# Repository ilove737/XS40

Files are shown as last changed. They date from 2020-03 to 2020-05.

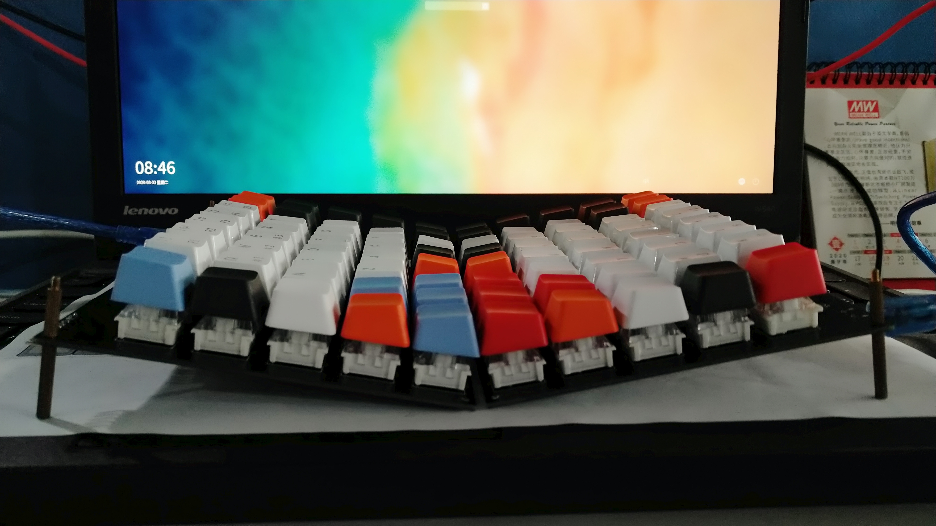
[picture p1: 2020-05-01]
doc/a8b779794b4cff2eecfce481d46be4e.jpg

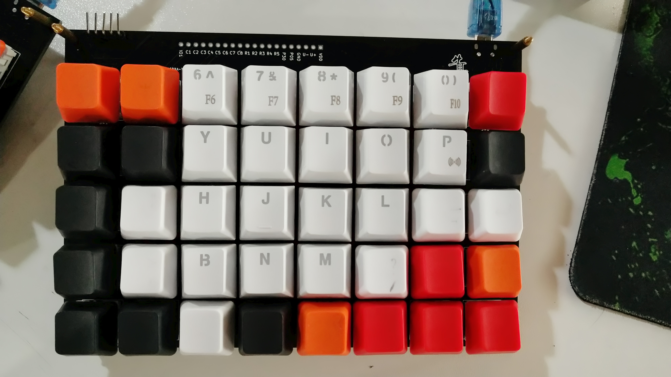
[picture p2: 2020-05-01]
doc/74a61ceb1c933b0123dbee454cc0db6.jpg

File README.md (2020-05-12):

# XS40

#### 介绍
80键分体键盘，采用非常便宜的单片机和USB HID接口芯片。目的就是打造一款低成本的机械键盘DIY方案。

hard 文件夹内是键盘的硬件设计文档，PCB设计使用的是KiCad开源软件。

soft 文件夹内是键盘的软件实现。逻辑部分用的是新唐的N76E003单片机。USB接口使用的是 CH9328 USB HID 芯片。

目前的键位设计可以通过  http://www.keyboard-layout-editor.com/#/  站点查看。
打开上述网页点击“Raw data”选项卡，粘贴一下内容即可渲染出键位设计。如有对键位设计有建议的可以在评论区留言，谢谢！
```
[{c:"#6495ed"},"Esc",{c:"#cccccc"},"!\n1","@\n2","#\n3","$\n4","%\n5",{c:"#ff4500"},"~\n`","*",{x:1},"_","+",{c:"#cccccc"},"^\n6","&\n7","*\n8","(\n9",")\n0",{c:"#bb0000"},"Bs"],
[{c:"#444444"},"Tab",{c:"#cccccc"},"Q","W","E","R","T",{c:"#444444"},"{\n[","}\n]",{x:1},"+\n=","|\n\\",{c:"#cccccc"},"Y","U","I","O","P",{c:"#444444"},"del"],
[{c:"#cccccc"},"Caps Lock","A","S","D","F","G","(",{c:"#444444"},")",{x:1},":\n;",{c:"#cccccc"},"<\n,","H","J","K","L","_\n-","Enter"],
[{c:"#ff4500"},"Shift",{c:"#6495ed"},"@",{c:"#cccccc"},"Z","X","C","V","&",{c:"#444444"},"#",{x:1},"\"\n'",{c:"#cccccc"},">\n.","B","N","M","?\n/",{c:"#bb0000"},"↑",{c:"#ff4500"},"RShift"],
[{c:"#6495ed"},"Fn0","Win","Alt",{c:"#ff4500"},"Shift",{c:"#cccccc"},"Space",{c:"#444444"},"Ctrl","~","!",{x:1},"%","?","Ctrl",{c:"#cccccc"},"Space",{c:"#ff4500"},"Fn0",{c:"#bb0000"},"←","↓","→"],

[{y:0.5,c:"#6495ed"},"F0",{c:"#cccccc"},"F1","F2","F3","F4","F5",{c:"#ff4500"},"Num Lock","",{x:1},"","",{c:"#cccccc"},"F6","F7","F8","F9","F10",{c:"#bb0000"},""],
[{c:"#444444"},"select",{c:"#cccccc"},"F11","F12","mail",{a:7},"","",{c:"#444444",a:4},"","",{x:1},"","",{c:"#cccccc"},"7\nHome",{a:4},"8\n↑","|",{a:4},"/","",{c:"#444444"},""],
[{c:"#cccccc"},"prev","play","next","stop",{a:7},"","",{a:4},"",{c:"#444444"},"",{x:1},"",{c:"#cccccc"},"","4\n←",{a:4},"\"",{a:4},":",{a:4},"*","",""],
[{c:"#ff4500",a:4},"vol dn",{c:"#6495ed"},"mute",{c:"#cccccc"},"vol up","app",{a:7},"","",{a:4},"",{c:"#444444"},"",{x:1},"",{c:"#cccccc"},"","1\nEnd","{","}","-",{c:"#bb0000",a:4},"",{c:"#ff4500"},""],
[{c:"#6495ed"},"Fn0","Fn2","Fn4",{c:"#ff4500",a:7},"",{c:"#cccccc"},"",{c:"#444444"},"",{a:4},"","",{x:1},"","","PEnter",{c:"#cccccc"},"0\nIns",{c:"#ff4500"},"Fn0",{c:"#bb0000"},"+","",""]

```

#### 展示
输入图片说明
输入图片说明
输入图片说明
输入图片说明

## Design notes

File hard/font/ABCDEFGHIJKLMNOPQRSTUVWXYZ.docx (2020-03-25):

ABCDEFGHIJKLMNOPQRSTUVWXYZ

abcdefghijklmnopqrstuvwxyz

!@#$%^&*()_+-=[]{}\|;:’”,<.>/?~`

shift tab caps ctrl alt esc enter fn backspace delete home end insert

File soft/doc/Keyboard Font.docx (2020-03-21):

Keyboard Font

ABCDEFGHIJKLMNOPQRSTUVWXYZ

abcdefghijklmnopqrstuvwxyz

!@#$%^&*()_+-=[]{};:’”,<.>/?`~\|

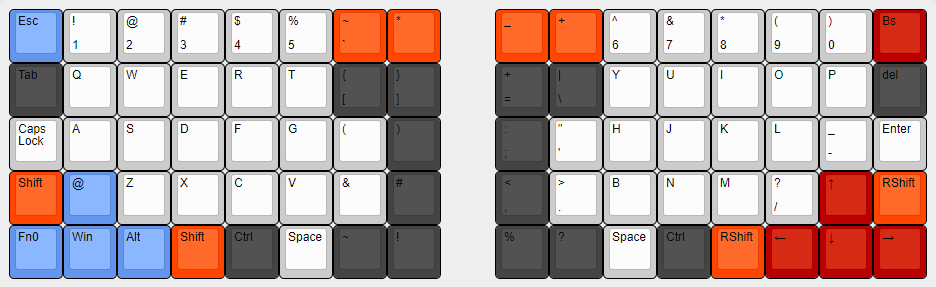
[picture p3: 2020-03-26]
soft/doc/keyMap.png

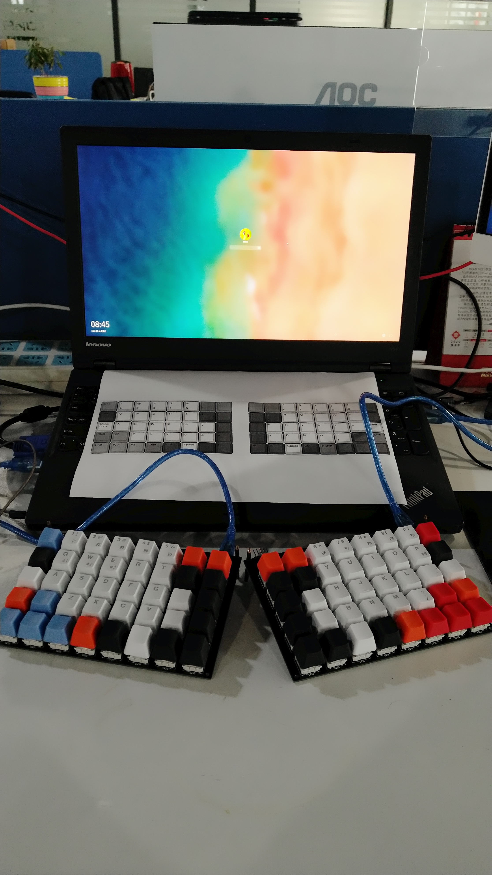
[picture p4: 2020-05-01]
doc/43c635f29237a9f031e426376ea0fd5.jpg

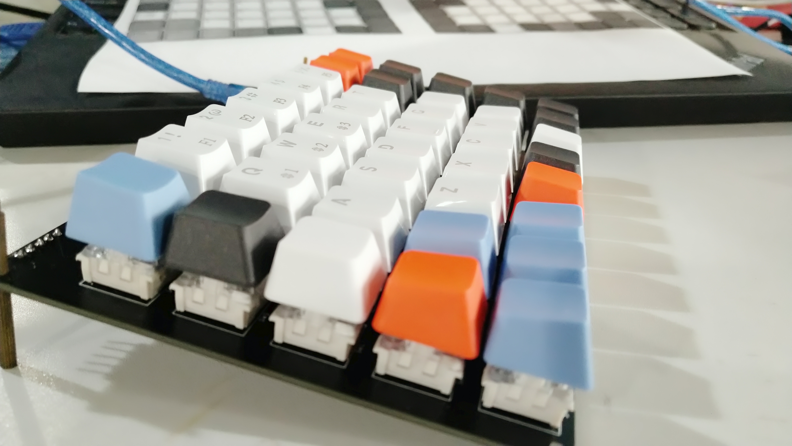
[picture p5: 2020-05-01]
doc/b146eeb9497ea70faab857080b56009.jpg

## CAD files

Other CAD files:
soft/Sample_Code/GPIO/Output/STARTUP.obj
soft/Sample_Code/GPIO/Output/Common.obj
soft/Sample_Code/GPIO/Output/Delay.obj
soft/Sample_Code/GPIO/Output/GPIO.obj

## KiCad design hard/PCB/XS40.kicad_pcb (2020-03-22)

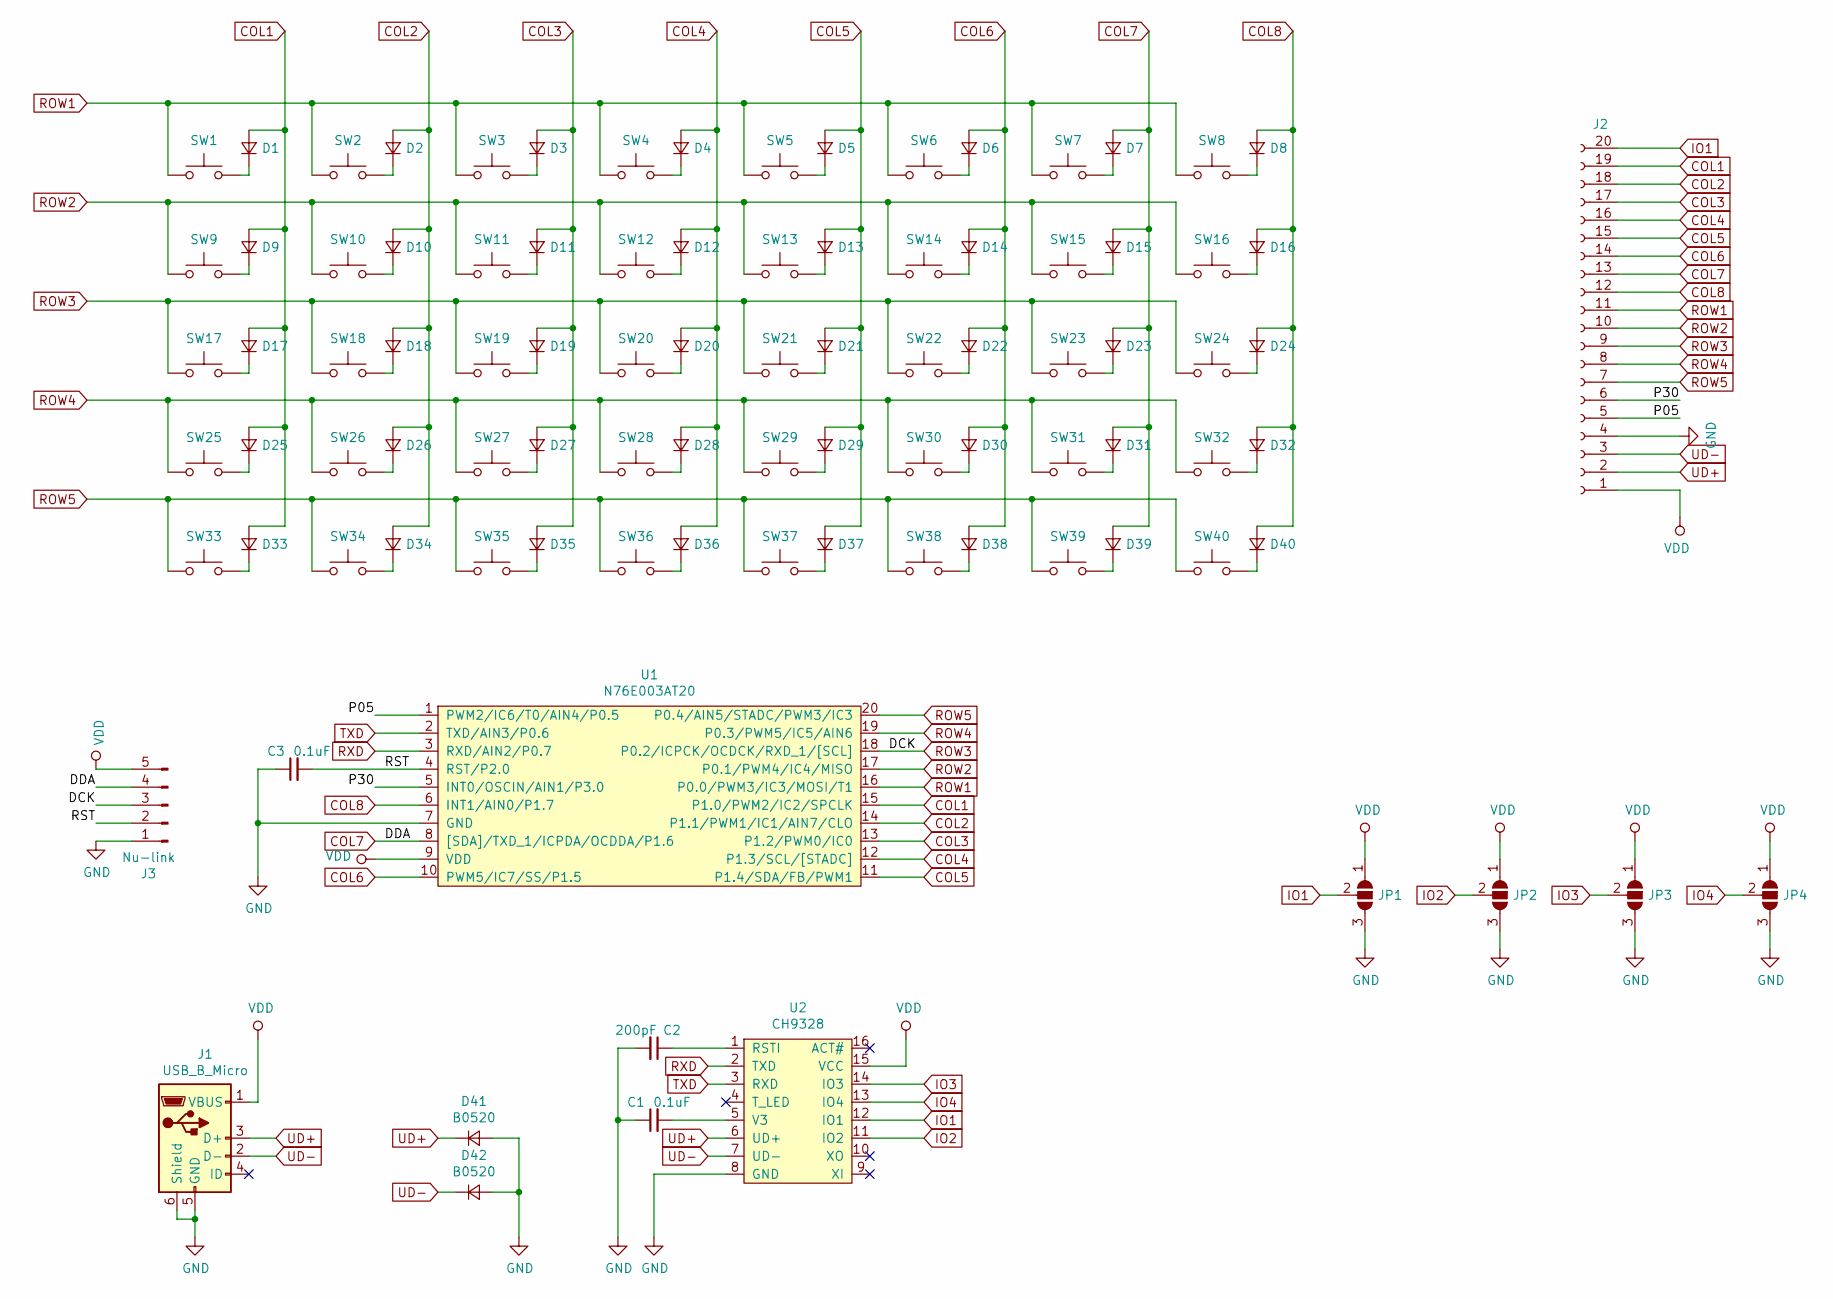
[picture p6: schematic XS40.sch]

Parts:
C1, C3: 0.1uF; C_0603_1608Metric
C2: 200pF; C_0603_1608Metric
D1, D2, D3, D4, D5, D6, D7, D8, D9, D10, D11, D12, D13, D14, D15, D16, D17, D18, D19, D20, D21, D22, D23, D24, D25, D26, D27, D28, D29, D30, D31, D32, D33, D34, D35, D36, D37, D38, D39, D40: D_Small; D_1206_3216Metric
D41, D42: B0520; D_SOD-123
J1: USB_B_Micro; USB_Micro-B_Molex-105017-0001
J2: Conn_01x20_Female; PinSocket_1x20_P2.54mm_Vertical
J3: Nu-link; PinSocket_1x05_P2.54mm_Vertical
JP1, JP2, JP3, JP4: SolderJumper_3_Open; SolderJumper-3_P1.3mm_Open_RoundedPad1.0x1.5mm_NumberLabels
SW1, SW2, SW3, SW4, SW5, SW6, SW7, SW8, SW9, SW10, SW11, SW12, SW13, SW14, SW15, SW16, SW17, SW18, SW19, SW20, SW21, SW22, SW23, SW24, SW25, SW26, SW27, SW28, SW29, SW30, SW31, SW32, SW33, SW34, SW35, SW36, SW37, SW38, SW39, SW40: SW_Push; SW_Cherry_MX_1.00u_PCB
U1: N76E003AT20; TSSOP-20_4.4x6.5mm_P0.65mm
U2: CH9328; SOP-16_4.55x10.3mm_P1.27mm

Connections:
/P05: J2.5, U1.1 (PWM2/IC6/T0/AIN4/P0.5)
/P30: J2.6, U1.5 (INT0/OSCIN/AIN1/P3.0)
/RST: C3.2, J3.2, U1.4 (RST/P2.0)
COL1: D1.2 (A), D9.2 (A), D17.2 (A), D25.2 (A), D33.2 (A), J2.19, U1.15 (P1.0/PWM2/IC2/SPCLK)
COL2: D2.2 (A), D10.2 (A), D18.2 (A), D26.2 (A), D34.2 (A), J2.18, U1.14 (P1.1/PWM1/IC1/AIN7/CLO)
COL3: D3.2 (A), D11.2 (A), D19.2 (A), D27.2 (A), D35.2 (A), J2.17, U1.13 (P1.2/PWM0/IC0)
COL4: D4.2 (A), D12.2 (A), D20.2 (A), D28.2 (A), D36.2 (A), J2.16, U1.12 (P1.3/SCL/[STADC])
COL5: D5.2 (A), D13.2 (A), D21.2 (A), D29.2 (A), D37.2 (A), J2.15, U1.11 (P1.4/SDA/FB/PWM1)
COL6: D6.2 (A), D14.2 (A), D22.2 (A), D30.2 (A), D38.2 (A), J2.14, U1.10 (PWM5/IC7/SS/P1.5)
COL7: D7.2 (A), D15.2 (A), D23.2 (A), D31.2 (A), D39.2 (A), J2.13, J3.4, U1.8 ([SDA]/TXD_1/ICPDA/OCDDA/P1.6)
COL8: D8.2 (A), D16.2 (A), D24.2 (A), D32.2 (A), D40.2 (A), J2.12, U1.6 (INT1/AIN0/P1.7)
GND: C1.1, C2.2, C3.1, D41.2 (A), D42.2 (A), J1.5 (GND), J1.6 (Shield), J2.4, J3.1, JP1.3 (B), JP2.3 (B), JP3.3 (B), JP4.3 (B), U1.7 (GND), U2.8 (GND)
IO1: J2.20, JP1.2 (C), U2.12 (IO1)
IO2: JP2.2 (C), U2.11 (IO2)
IO3: JP3.2 (C), U2.14 (IO3)
IO4: JP4.2 (C), U2.13 (IO4)
unnamed: C1.2, U2.5 (V3)
unnamed: C2.1, U2.1 (RSTI)
unnamed: D1.1 (K), SW1.2
unnamed: D2.1 (K), SW2.2
unnamed: D3.1 (K), SW3.2
unnamed: D4.1 (K), SW4.2
unnamed: D5.1 (K), SW5.2
unnamed: D6.1 (K), SW6.2
unnamed: D7.1 (K), SW7.2
unnamed: D8.1 (K), SW8.2
unnamed: D9.1 (K), SW9.2
unnamed: D10.1 (K), SW10.2
unnamed: D11.1 (K), SW11.2
unnamed: D12.1 (K), SW12.2
unnamed: D13.1 (K), SW13.2
unnamed: D14.1 (K), SW14.2
unnamed: D15.1 (K), SW15.2
unnamed: D16.1 (K), SW16.2
unnamed: D17.1 (K), SW17.2
unnamed: D18.1 (K), SW18.2
unnamed: D19.1 (K), SW19.2
unnamed: D20.1 (K), SW20.2
unnamed: D21.1 (K), SW21.2
unnamed: D22.1 (K), SW22.2
unnamed: D23.1 (K), SW23.2
unnamed: D24.1 (K), SW24.2
unnamed: D25.1 (K), SW25.2
unnamed: D26.1 (K), SW26.2
unnamed: D27.1 (K), SW27.2
unnamed: D28.1 (K), SW28.2
unnamed: D29.1 (K), SW29.2
unnamed: D30.1 (K), SW30.2
unnamed: D31.1 (K), SW31.2
unnamed: D32.1 (K), SW32.2
unnamed: D33.1 (K), SW33.2
unnamed: D34.1 (K), SW34.2
unnamed: D35.1 (K), SW35.2
unnamed: D36.1 (K), SW36.2
unnamed: D37.1 (K), SW37.2
unnamed: D38.1 (K), SW38.2
unnamed: D39.1 (K), SW39.2
unnamed: D40.1 (K), SW40.2
ROW1: J2.11, SW1.1, SW2.1, SW3.1, SW4.1, SW5.1, SW6.1, SW7.1, SW8.1, U1.16 (P0.0/PWM3/IC3/MOSI/T1)
ROW2: J2.10, SW9.1, SW10.1, SW11.1, SW12.1, SW13.1, SW14.1, SW15.1, SW16.1, U1.17 (P0.1/PWM4/IC4/MISO)
ROW3: J2.9, J3.3, SW17.1, SW18.1, SW19.1, SW20.1, SW21.1, SW22.1, SW23.1, SW24.1, U1.18 (P0.2/ICPCK/OCDCK/RXD_1/[SCL])
ROW4: J2.8, SW25.1, SW26.1, SW27.1, SW28.1, SW29.1, SW30.1, SW31.1, SW32.1, U1.19 (P0.3/PWM5/IC5/AIN6)
ROW5: J2.7, SW33.1, SW34.1, SW35.1, SW36.1, SW37.1, SW38.1, SW39.1, SW40.1, U1.20 (P0.4/AIN5/STADC/PWM3/IC3)
RXD: U1.3 (RXD/AIN2/P0.7), U2.2 (TXD)
TXD: U1.2 (TXD/AIN3/P0.6), U2.3 (RXD)
UD+: D41.1 (K), J1.3 (D+), J2.2, U2.6 (UD+)
UD-: D42.1 (K), J1.2 (D-), J2.3, U2.7 (UD-)
VDD: J1.1 (VBUS), J2.1, J3.5, JP1.1 (A), JP2.1 (A), JP3.1 (A), JP4.1 (A), U1.9 (VDD), U2.15 (VCC)

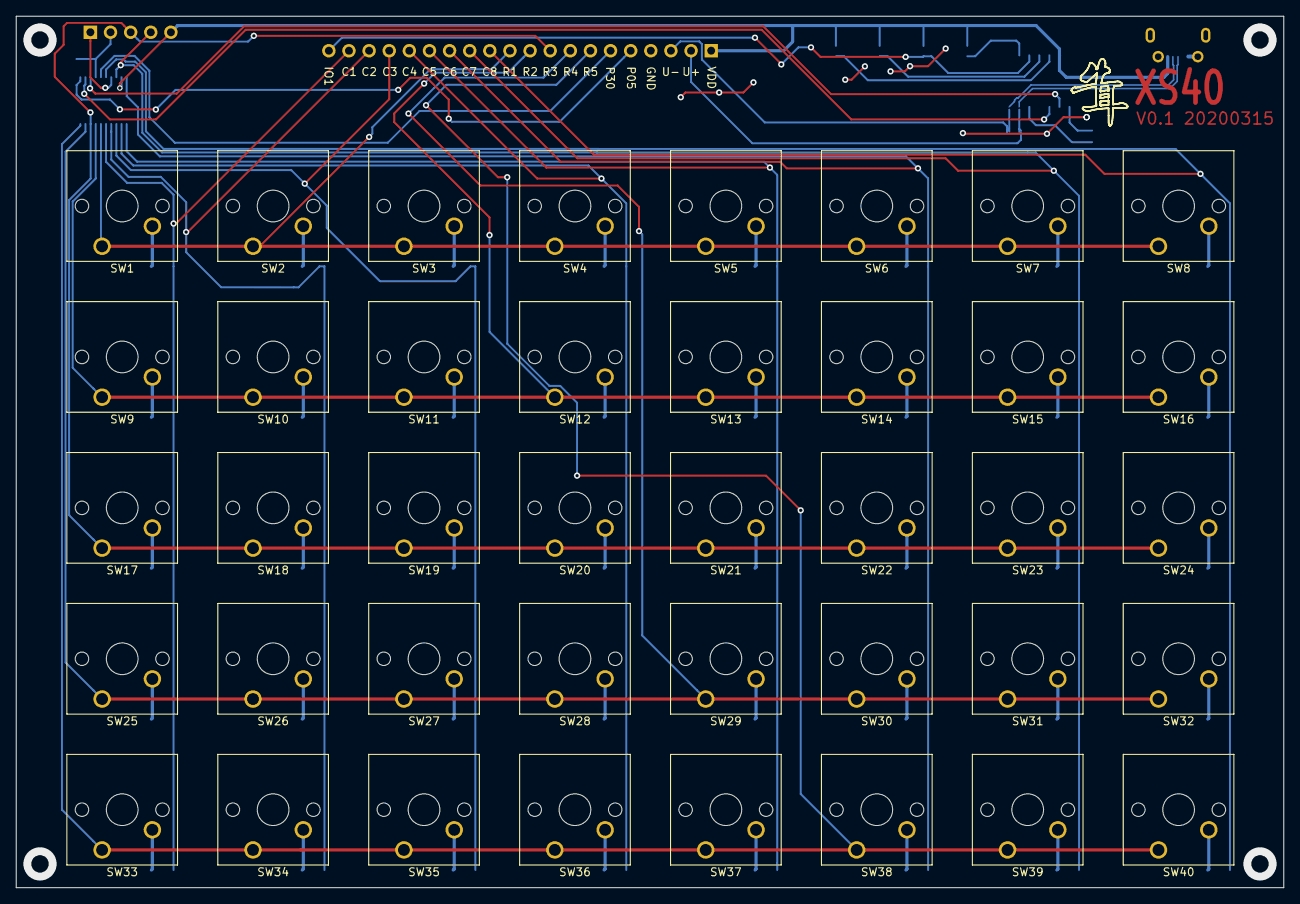
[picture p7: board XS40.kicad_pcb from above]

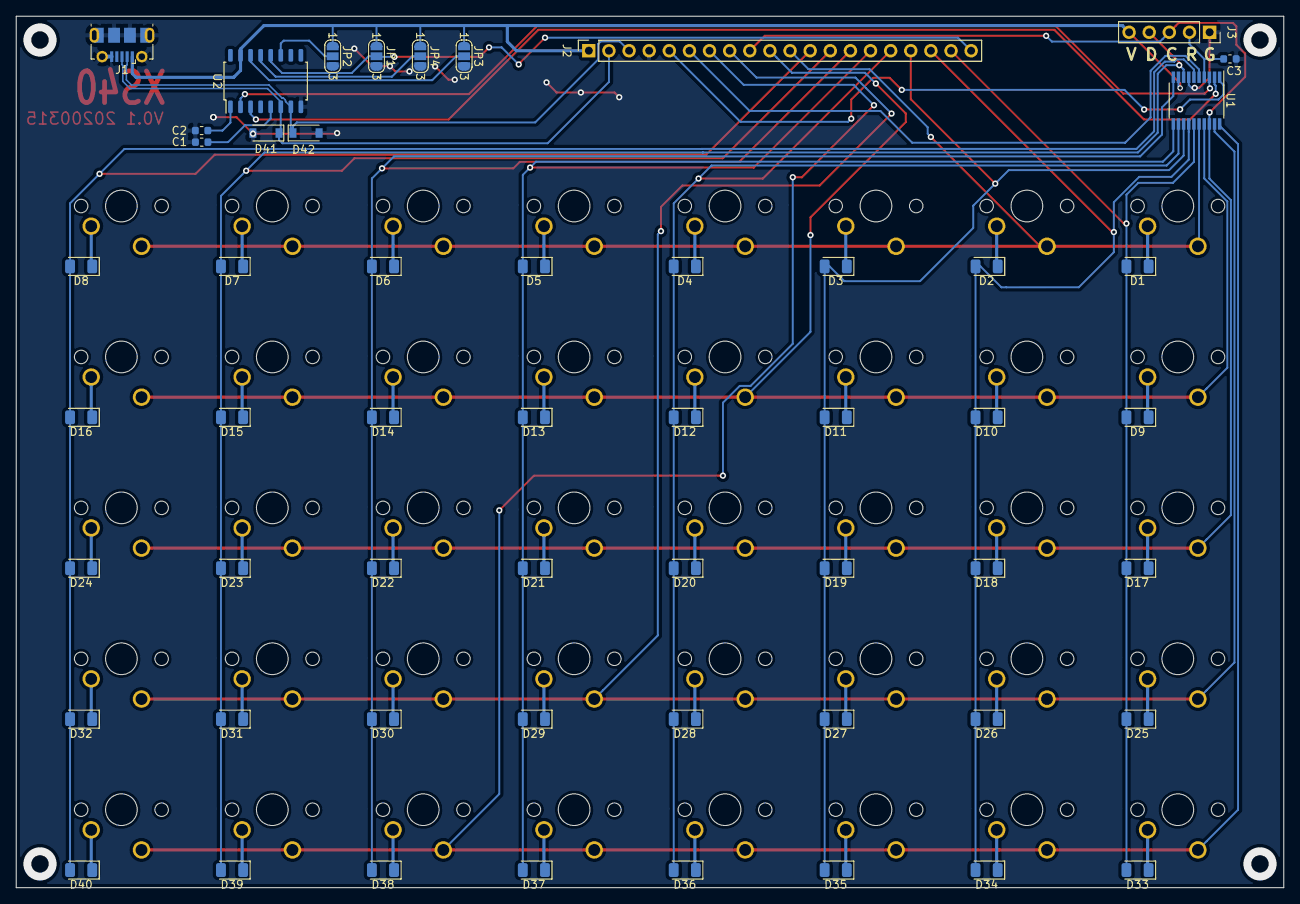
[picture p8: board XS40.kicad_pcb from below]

Board: 2 copper layers, 160.0 x 110.0 mm, 94 parts (54 on the bottom side), 68 nets.

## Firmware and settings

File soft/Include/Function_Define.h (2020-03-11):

#include <intrins.h>
#include <stdio.h>

#define nop _nop_();


//16 --> 8 x 2
#define HIBYTE(v1)              ((UINT8)((v1)>>8))                      //v1 is UINT16
#define LOBYTE(v1)              ((UINT8)((v1)&0xFF))
//8 x 2 --> 16
#define MAKEWORD(v1,v2)         ((((UINT16)(v1))<<8)+(UINT16)(v2))      //v1,v2 is UINT8
//8 x 4 --> 32
#define MAKELONG(v1,v2,v3,v4)   (UINT32)((v1<<32)+(v2<<16)+(v3<<8)+v4)  //v1,v2,v3,v4 is UINT8
//32 --> 16 x 2
#define YBYTE1(v1)              ((UINT16)((v1)>>16))                    //v1 is UINT32
#define YBYTE0(v1)              ((UINT16)((v1)&0xFFFF))
//32 --> 8 x 4
#define TBYTE3(v1)              ((UINT8)((v1)>>24))                     //v1 is UINT32
#define TBYTE2(v1)              ((UINT8)((v1)>>16))
#define TBYTE1(v1)              ((UINT8)((v1)>>8)) 
#define TBYTE0(v1)              ((UINT8)((v1)&0xFF))

#define SET_BIT0        0x01
#define SET_BIT1        0x02
#define SET_BIT2        0x04
#define SET_BIT3        0x08
#define SET_BIT4        0x10
#define SET_BIT5        0x20
#define SET_BIT6        0x40
#define SET_BIT7        0x80
#define SET_BIT8        0x0100
#define SET_BIT9        0x0200
#define SET_BIT10       0x0400
#define SET_BIT11       0x0800
#define SET_BIT12       0x1000
#define SET_BIT13       0x2000
#define SET_BIT14       0x4000
#define SET_BIT15       0x8000

#define CLR_BIT0        0xFE
#define CLR_BIT1        0xFD
#define CLR_BIT2        0xFB
#define CLR_BIT3        0xF7
#define CLR_BIT4        0xEF
#define CLR_BIT5        0xDF
#define CLR_BIT6        0xBF
#define CLR_BIT7        0x7F

#define CLR_BIT8        0xFEFF
#define CLR_BIT9        0xFDFF
#define CLR_BIT10       0xFBFF
#define CLR_BIT11       0xF7FF
#define CLR_BIT12       0xEFFF
#define CLR_BIT13       0xDFFF
#define CLR_BIT14       0xBFFF
#define CLR_BIT15       0x7FFF

#define FAIL            1
#define PASS            0

/*****************************************************************************************
* For GPIO INIT setting 
*****************************************************************************************/
//------------------- Define Port as Quasi mode  -------------------
#define P00_Quasi_Mode				P0M1&=~SET_BIT0;P0M2&=~SET_BIT0
#define P01_Quasi_Mode				P0M1&=~SET_BIT1;P0M2&=~SET_BIT1
#define P02_Quasi_Mode				P0M1&=~SET_BIT2;P0M2&=~SET_BIT2
#define P03_Quasi_Mode				P0M1&=~SET_BIT3;P0M2&=~SET_BIT3
#define P04_Quasi_Mode				P0M1&=~SET_BIT4;P0M2&=~SET_BIT4
#define P05_Quasi_Mode				P0M1&=~SET_BIT5;P0M2&=~SET_BIT5
#define P06_Quasi_Mode				P0M1&=~SET_BIT6;P0M2&=~SET_BIT6
#define P07_Quasi_Mode				P0M1&=~SET_BIT7;P0M2&=~SET_BIT7
#define P10_Quasi_Mode				P1M1&=~SET_BIT0;P1M2&=~SET_BIT0
#define P11_Quasi_Mode				P1M1&=~SET_BIT1;P1M2&=~SET_BIT1
#define P12_Quasi_Mode				P1M1&=~SET_BIT2;P1M2&=~SET_BIT2
#define P13_Quasi_Mode				P1M1&=~SET_BIT3;P1M2&=~SET_BIT3
#define P14_Quasi_Mode				P1M1&=~SET_BIT4;P1M2&=~SET_BIT4
#define P15_Quasi_Mode				P1M1&=~SET_BIT5;P1M2&=~SET_BIT5
#define P16_Quasi_Mode				P1M1&=~SET_BIT6;P1M2&=~SET_BIT6
#define P17_Quasi_Mode				P1M1&=~SET_BIT7;P1M2&=~SET_BIT7
#define P30_Quasi_Mode				P3M1&=~SET_BIT0;P3M2&=~SET_BIT0
//------------------- Define Port as Push Pull mode -------------------
#define P00_PushPull_Mode			P0M1&=~SET_BIT0;P0M2|=SET_BIT0
#define P01_PushPull_Mode			P0M1&=~SET_BIT1;P0M2|=SET_BIT1
#define P02_PushPull_Mode			P0M1&=~SET_BIT2;P0M2|=SET_BIT2
#define P03_PushPull_Mode			P0M1&=~SET_BIT3;P0M2|=SET_BIT3
#define P04_PushPull_Mode			P0M1&=~SET_BIT4;P0M2|=SET_BIT4
#define P05_PushPull_Mode			P0M1&=~SET_BIT5;P0M2|=SET_BIT5
#define P06_PushPull_Mode			P0M1&=~SET_BIT6;P0M2|=SET_BIT6
#define P07_PushPull_Mode			P0M1&=~SET_BIT7;P0M2|=SET_BIT7
#define P10_PushPull_Mode			P1M1&=~SET_BIT0;P1M2|=SET_BIT0
#define P11_PushPull_Mode			P1M1&=~SET_BIT1;P1M2|=SET_BIT1
#define P12_PushPull_Mode			P1M1&=~SET_BIT2;P1M2|=SET_BIT2
#define P13_PushPull_Mode			P1M1&=~SET_BIT3;P1M2|=SET_BIT3
#define P14_PushPull_Mode			P1M1&=~SET_BIT4;P1M2|=SET_BIT4
#define P15_PushPull_Mode			P1M1&=~SET_BIT5;P1M2|=SET_BIT5
#define P16_PushPull_Mode			P1M1&=~SET_BIT6;P1M2|=SET_BIT6
#define P17_PushPull_Mode			P1M1&=~SET_BIT7;P1M2|=SET_BIT7
#define P30_PushPull_Mode			P3M1&=~SET_BIT0;P3M2|=SET_BIT0
#define GPIO1_PushPull_Mode		P1M1&=~SET_BIT0;P1M2|=SET_BIT0
//------------------- Define Port as Input Only mode -------------------
#define P00_Input_Mode				P0M1|=SET_BIT0;P0M2&=~SET_BIT0
#define P01_Input_Mode				P0M1|=SET_BIT1;P0M2&=~SET_BIT1
#define P02_Input_Mode				P0M1|=SET_BIT2;P0M2&=~SET_BIT2
#define P03_Input_Mode				P0M1|=SET_BIT3;P0M2&=~SET_BIT3
#define P04_Input_Mode				P0M1|=SET_BIT4;P0M2&=~SET_BIT4
#define P05_Input_Mode				P0M1|=SET_BIT5;P0M2&=~SET_BIT5
#define P06_Input_Mode				P0M1|=SET_BIT6;P0M2&=~SET_BIT6
#define P07_Input_Mode				P0M1|=SET_BIT7;P0M2&=~SET_BIT7
#define P10_Input_Mode				P1M1|=SET_BIT0;P1M2&=~SET_BIT0
#define P11_Input_Mode				P1M1|=SET_BIT1;P1M2&=~SET_BIT1
#define P12_Input_Mode				P1M1|=SET_BIT2;P1M2&=~SET_BIT2
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

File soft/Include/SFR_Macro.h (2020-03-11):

/**** P0		80H *****/
#define set_P00			P00		=		1
#define set_P01			P01		=		1
#define set_P02			P02		=		1
#define set_P03			P03		=		1
#define set_P04			P04		=		1
#define set_P05			P05		=		1
#define set_P06			P06		=		1
#define set_P07			P07		=		1

#define clr_P00			P00		=		0
#define clr_P01			P01		=		0
#define clr_P02			P02		=		0
#define clr_P03			P03		=		0
#define clr_P04			P04		=		0
#define clr_P05			P05		=		0
#define clr_P06			P06		=		0
#define clr_P07			P07		=		0

//**** SP  	81H **** 
//**** DPH  82H **** 
//**** DPL  83H **** 
//**** RWK  86H **** 

//**** PCON	87H *****
#define set_SMOD    PCON    |= SET_BIT7
#define set_SMOD0   PCON    |= SET_BIT6
#define set_POF     PCON    |= SET_BIT4
#define set_GF1     PCON    |= SET_BIT3
#define set_GF0     PCON    |= SET_BIT2 
#define set_PD      PCON    |= SET_BIT1
#define set_IDL    	PCON    |= SET_BIT0
                            
#define clr_SMOD    PCON    &= ~SET_BIT7
#define clr_SMOD0   PCON    &= ~SET_BIT6
#define clr_POF     PCON    &= ~SET_BIT4
#define clr_GF1     PCON    &= ~SET_BIT3
#define clr_GF0     PCON    &= ~SET_BIT2 
#define clr_PD      PCON    &= ~SET_BIT1
#define clr_IDL    	PCON    &= ~SET_BIT0

/**** TCON		88H ****/
#define set_TF1			TF1		=		1
#define set_TR1			TR1		=		1
#define set_TF0			TF0		=		1
#define set_TR0			TR0		=		1
#define set_IE1			IE1		=		1
#define set_IT1			IT1		=		1
#define set_IE0			IE0		=		1
#define set_IT0			IT0		=		1

#define clr_TF1			TF1		=		0
#define clr_TR1			TR1		=		0
#define clr_TF0			TF0		=		0
#define clr_TR0			TR0		=		0
#define clr_IE1			IE1		=		0
#define clr_IT1			IT1		=		0
#define clr_IE0			IE0		=		0
#define clr_IT0			IT0		=		0

//**** TMOD		89H **** 
#define set_GATE_T1 	TMOD 		|= 	SET_BIT7
#define set_CT_T1 		TMOD   	|= 	SET_BIT6
#define set_M1_T1 		TMOD  	|= 	SET_BIT5
#define set_M0_T1 		TMOD   	|= 	SET_BIT4
#define set_GATE_T0 	TMOD 		|= 	SET_BIT3
#define set_CT_T0 		TMOD 	  |= 	SET_BIT2
#define set_M1_T0 		TMOD   	|= 	SET_BIT1
#define set_M0_T0 		TMOD   	|= 	SET_BIT0
                            
#define clr_GATE_T1 	TMOD 		&= 	~SET_BIT7
#define clr_CT_T1 		TMOD   	&= 	~SET_BIT6
#define clr_M1_T1 		TMOD   	&= 	~SET_BIT5
#define clr_M0_T1 		TMOD   	&= 	~SET_BIT4
#define clr_GATE_T0 	TMOD 		&= 	~SET_BIT3
#define clr_CT_T0 		TMOD   	&= 	~SET_BIT2
#define clr_M1_T0 		TMOD   	&= 	~SET_BIT1
#define clr_M0_T0 		TMOD   	&= 	~SET_BIT0

//**** TH1		8AH **** 
//**** TH0		8BH **** 
//**** TL1		8CH	**** 
//**** TL0		8DH **** 

//**** CKCON	8EH ****
#define set_PWMCKS  CKCON   |= SET_BIT6
#define set_T1M     CKCON   |= SET_BIT4
#define set_T0M     CKCON   |= SET_BIT3
#define set_CLOEN   CKCON   |= SET_BIT1
                            
#define clr_PWMCKS  CKCON   &= ~SET_BIT6
#define clr_T1M     CKCON   &= ~SET_BIT4
#define clr_T0M     CKCON   &= ~SET_BIT3
#define clr_CLOEN   CKCON   &= ~SET_BIT1

//**** WKCON	8FH ****
#define set_WKTCK   WKCON   |= SET_BIT5
#define set_WKTF    WKCON   |= SET_BIT4
#define set_WKTR    WKCON   |= SET_BIT3
#define set_WKPS2   WKCON   |= SET_BIT2
#define set_WKPS1   WKCON   |= SET_BIT1
#define set_WKPS0   WKCON   |= SET_BIT0
                            
#define clr_WKTCK   WKCON   &= ~SET_BIT5
#define clr_WKTF    WKCON   &= ~SET_BIT4
#define clr_WKTR    WKCON   &= ~SET_BIT3
#define clr_WKPS2   WKCON   &= ~SET_BIT2
#define clr_WKPS1   WKCON   &= ~SET_BIT1
#define clr_WKPS0   WKCON   &= ~SET_BIT0

/**** P1		90H *****/
#define set_P10			P10		=		1
#define set_P11			P11		=		1
#define set_P12			P12		=		1
#define set_P13			P13		=		1
#define set_P14			P14		=		1
#define set_P15			P15		=		1
#define set_P16			P16		=		1
#define set_P17			P17		=		1

#define clr_P10			P10		=		0
#define clr_P11			P11		=		0
#define clr_P12			P12		=		0
#define clr_P13			P13		=		0
#define clr_P14			P14		=		0
#define clr_P15			P15		=		0
#define clr_P16			P16		=		0
#define clr_P17			P17		=		0

//****SFRS		91H ****
#define set_SFRPAGE  BIT_TMP=EA;EA=0;TA=0xAA;TA=0x55;SFRS|=SET_BIT0;EA=BIT_TMP
#define clr_SFRPAGE  BIT_TMP=EA;EA=0;TA=0xAA;TA=0x55;SFRS&=~SET_BIT0;EA=BIT_TMP

//****CAPCON0	92H ****
#define set_CAPEN2  CAPCON0 |= SET_BIT6
#define set_CAPEN1  CAPCON0 |= SET_BIT5
#define set_CAPEN0  CAPCON0 |= SET_BIT4
#define set_CAPF2   CAPCON0 |= SET_BIT2
#define set_CAPF1   CAPCON0 |= SET_BIT1
#define set_CAPF0   CAPCON0 |= SET_BIT0

#define clr_CAPEN2  CAPCON0 &= ~SET_BIT6
#define clr_CAPEN1  CAPCON0 &= ~SET_BIT5
#define clr_CAPEN0  CAPCON0 &= ~SET_BIT4
#define clr_CAPF2   CAPCON0 &= ~SET_BIT2
#define clr_CAPF1   CAPCON0 &= ~SET_BIT1
#define clr_CAPF0   CAPCON0 &= ~SET_BIT0

//**** CAPCON1	93H ****
#define set_CAP2LS1 CAPCON1 |= SET_BIT5
#define set_CAP2LS0 CAPCON1 |= SET_BIT4
#define set_CAP1LS1 CAPCON1 |= SET_BIT3
#define set_CAP1LS0 CAPCON1 |= SET_BIT2
#define set_CAP0LS1 CAPCON1 |= SET_BIT1
#define set_CAP0LS0 CAPCON1 |= SET_BIT0

#define clr_CAP2LS1 CAPCON1 &= ~SET_BIT5
#define clr_CAP2LS0 CAPCON1 &= ~SET_BIT4
#define clr_CAP1LS1 CAPCON1 &= ~SET_BIT3
#define clr_CAP1LS0 CAPCON1 &= ~SET_BIT2
#define clr_CAP0LS1 CAPCON1 &= ~SET_BIT1
#define clr_CAP0LS0 CAPCON1 &= ~SET_BIT0

//**** CAPCON2		94H ****
#define set_ENF2  CAPCON2   |= SET_BIT6
#define set_ENF1  CAPCON2   |= SET_BIT5
#define set_ENF0  CAPCON2   |= SET_BIT4
                            
#define clr_ENF2  CAPCON2   &= ~SET_BIT6
#define clr_ENF1  CAPCON2   &= ~SET_BIT5
#define clr_ENF0  CAPCON2   &= ~SET_BIT4

//**** CKDIV		95H ****

//**** CKSWT		96H ****  TA protect register
#define set_HIRCST  BIT_TMP=EA;EA=0;TA=0xAA;TA=0x55;CKSWT|=SET_BIT5;EA=BIT_TMP;
#define set_LIRCST  BIT_TMP=EA;EA=0;TA=0xAA;TA=0x55;CKSWT|=SET_BIT4;EA=BIT_TMP;
#define set_ECLKST  BIT_TMP=EA;EA=0;TA=0xAA;TA=0x55;CKSWT|=SET_BIT3;EA=BIT_TMP;
#define set_OSC1    BIT_TMP=EA;EA=0;TA=0xAA;TA=0x55;CKSWT|=SET_BIT2;EA=BIT_TMP;
#define set_OSC0    BIT_TMP=EA;EA=0;TA=0xAA;TA=0x55;CKSWT|=SET_BIT1;EA=BIT_TMP;

#define clr_HIRCST  BIT_TMP=EA;EA=0;TA=0xAA;TA=0x55;CKSWT&=~SET_BIT5;EA=BIT_TMP;
#define clr_LIRCST  BIT_TMP=EA;EA=0;TA=0xAA;TA=0x55;CKSWT&=~SET_BIT4;EA=BIT_TMP;
#define clr_ECLKST  BIT_TMP=EA;EA=0;TA=0xAA;TA=0x55;CKSWT&=~SET_BIT3;EA=BIT_TMP;
#define clr_OSC1    BIT_TMP=EA;EA=0;TA=0xAA;TA=0x55;CKSWT&=~SET_BIT2;EA=BIT_TMP;
#define clr_OSC0    BIT_TMP=EA;EA=0;TA=0xAA;TA=0x55;CKSWT&=~SET_BIT1;EA=BIT_TMP;

//**** CKEN 	97H **** TA protect register
#define set_EXTEN1  BIT_TMP=EA;EA=0;TA=0xAA;TA=0x55;CKEN|=SET_BIT7;EA=BIT_TMP;
#define set_EXTEN0  BIT_TMP=EA;EA=0;TA=0xAA;TA=0x55;CKEN|=SET_BIT6;EA=BIT_TMP;
#define set_HIRCEN  BIT_TMP=EA;EA=0;TA=0xAA;TA=0x55;CKEN|=SET_BIT5;EA=BIT_TMP;
#define set_CKSWTF  BIT_TMP=EA;EA=0;TA=0xAA;TA=0x55;CKEN|=SET_BIT0;EA=BIT_TMP;
       
#define clr_EXTEN1  BIT_TMP=EA;EA=0;TA=0xAA;TA=0x55;CKEN&=~SET_BIT7;EA=BIT_TMP;
#define clr_EXTEN0  BIT_TMP=EA;EA=0;TA=0xAA;TA=0x55;CKEN&=~SET_BIT6;EA=BIT_TMP;
#define clr_HIRCEN  BIT_TMP=EA;EA=0;TA=0xAA;TA=0x55;CKEN&=~SET_BIT5;EA=BIT_TMP;
#define clr_CKSWTF  BIT_TMP=EA;EA=0;TA=0xAA;TA=0x55;CKEN&=~SET_BIT0;EA=BIT_TMP;
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

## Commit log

2020-03-11 完成按键扫描逻辑
    [GPIO.obj]
2020-03-11 打印出5个字节，包含40个键的状态。
    [GPIO.obj]
2020-03-12 对比所有按键的前后状态
2020-03-12 删除无用代码
2020-03-12 添加创建帧函数
2020-03-12 add keyMap.h
    [GPIO.obj]
2020-03-14 添加硬件设计文件
    [CH9328.xlsx, N76E003AT20.xlsx, XS40.dsn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]
2020-03-14 更新PCB图
    [GPIO.obj, XS40.kicad_pcb, XS40.sch]
2020-03-15 完成生成HID帧方法
    [GPIO.obj]
2020-03-15 PCB定稿；生成Gerber。
    [XS40-B_Cu.gbr, XS40-B_Mask.gbr, XS40-B_Paste.gbr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]
2020-03-21 硬件验证结束，单片机少一根GND线
    [Common.obj, Delay.obj, GPIO.obj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]
2020-03-21 定义右边的键位
2020-03-22 PCB添加了少的一根GND线，打包存档v0.1
    [Common.obj, Delay.obj, GPIO.obj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]
2020-03-22 修改键位
    [GPIO.obj]
2020-03-23 添加字体文件
    [CH9328.xlsx, N76E003AT20.xlsx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]
2020-03-25 实现了上档键的复合键；更新了键位布局。
    [Common.obj, Delay.obj, GPIO.obj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]
2020-03-29 规划Fn层键位
2020-04-06 新加STM32的实现
2020-04-14 添加了Fn键的功能；修改了部分键位排布。
    [Common.obj, Delay.obj, GPIO.obj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]
2020-04-30 删除STM32软件
2020-05-01 删除文件 .vscode
2020-05-01 添加图片
